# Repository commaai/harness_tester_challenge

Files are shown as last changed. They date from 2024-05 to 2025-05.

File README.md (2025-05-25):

<div align="center">
<h1>Harness Tester Challenge</h1>
<h3>
  <a href="https://comma.ai/leaderboard">Leaderboard</a>
  <span> · </span>
  <a href="https://comma.ai/jobs">comma.ai/jobs</a>
  <span> · </span>
  <a href="https://discord.comma.ai">Discord</a>
  <span> · </span>
  <a href="https://x.com/comma_ai">X</a>
</h3>
</div>

We (mock) designed a simple harness testing PCB and wrote some firmware for it. Unfortunately, this board was designed and firmware was written on a Monday morning.

<b>Can you figure out everything wrong with it?</b>

## The Harness Tester
We currently ship hundreds of [car-specific harnesses](https://www.comma.ai/shop/car-harness) to users every month, consisting of more than [40 different types](https://github.com/commaai/hardware/tree/master/harness/v3).

As a simple wiring harness, we expect them to have a near-zero failure rate, so good testing is critical.
This tester is designed to be capable of quickly verifying which pins are connected to which other pins.

A quick list of design goals is listed here:
- 12V DC input with transient and reverse polarity protection
- compatible with harnesses with up to 40 pins (through a pin header)
- start button and RGB LED are the user interface
- microSD card to store test results along with the current time (for statistical purposes)
- receive time by acquiring a GPS lock (*ok, yes, this is just to make the board and firmware more interesting*)

## The challenge
The challenge consists of 3 distinct parts, each riddled with more than a few bugs:
- Schematic ([PDF](./schematic.pdf) / [Web](https://kicanvas.org/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))
- PCB layout ([Gerbers](./gerbers.zip) / [Web](https://kicanvas.org/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))
- Firmware ([Source](./firmware/))

The board is designed in [KiCad 8](https://www.kicad.org/), and the full project is available in an [exported archive](./kicad_project.zip).

There are a handful of intentional, show-stopping bugs hidden in each part. Find them, and [send](https://forms.gle/US88Hg7UR6bBuW3BA) them over to us for verification!

We're not looking for improvements or fixes; just submit a list of bugs.

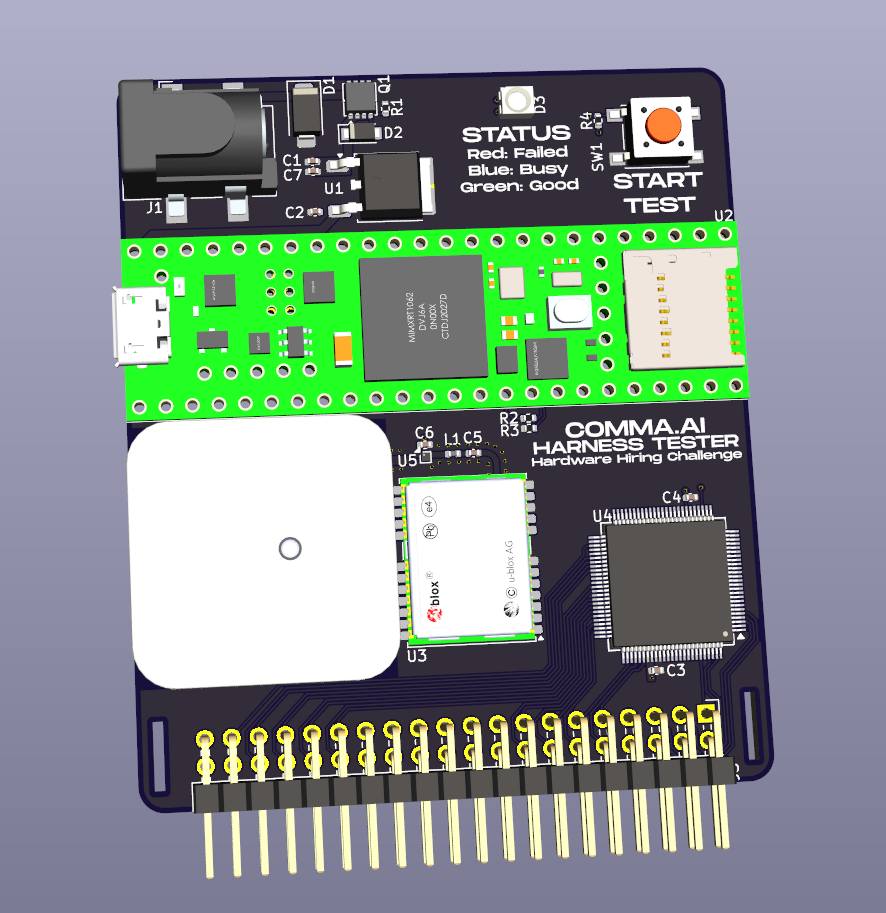
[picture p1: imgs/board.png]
PCB


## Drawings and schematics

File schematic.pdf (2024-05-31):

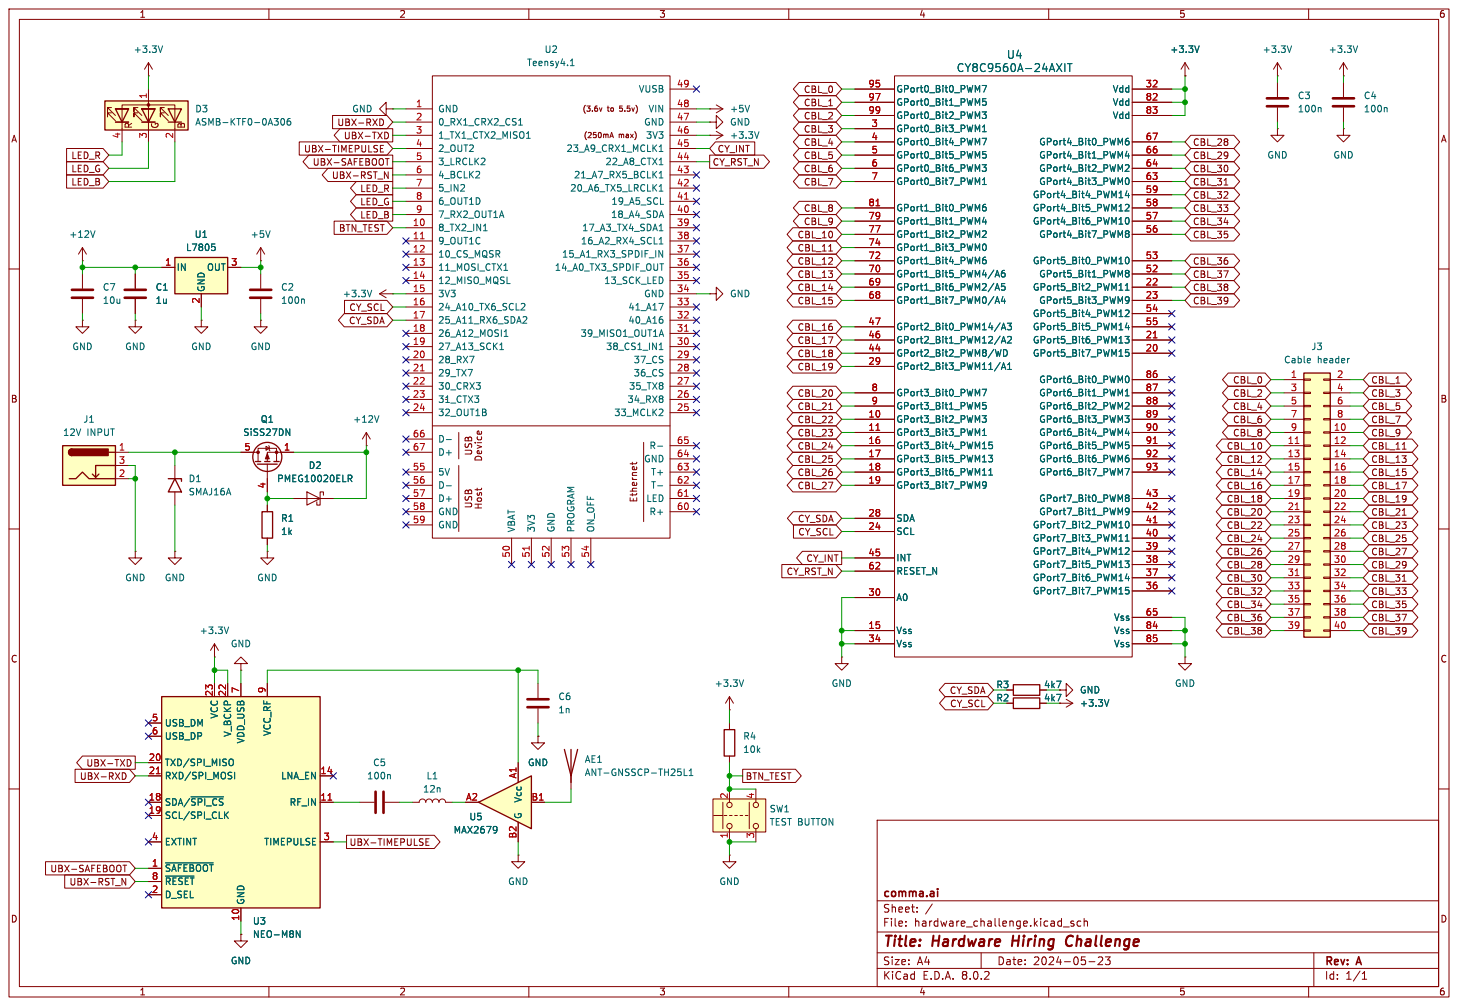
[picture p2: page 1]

UBX-TIMEPULSE UBX-TXD

3 4 SW1 TEST BUTTON GND GND

File: hardware_challenge.kicad_sch Sheet: / comma.ai C6

Id: 1/1 Title: Hardware Hiring Challenge

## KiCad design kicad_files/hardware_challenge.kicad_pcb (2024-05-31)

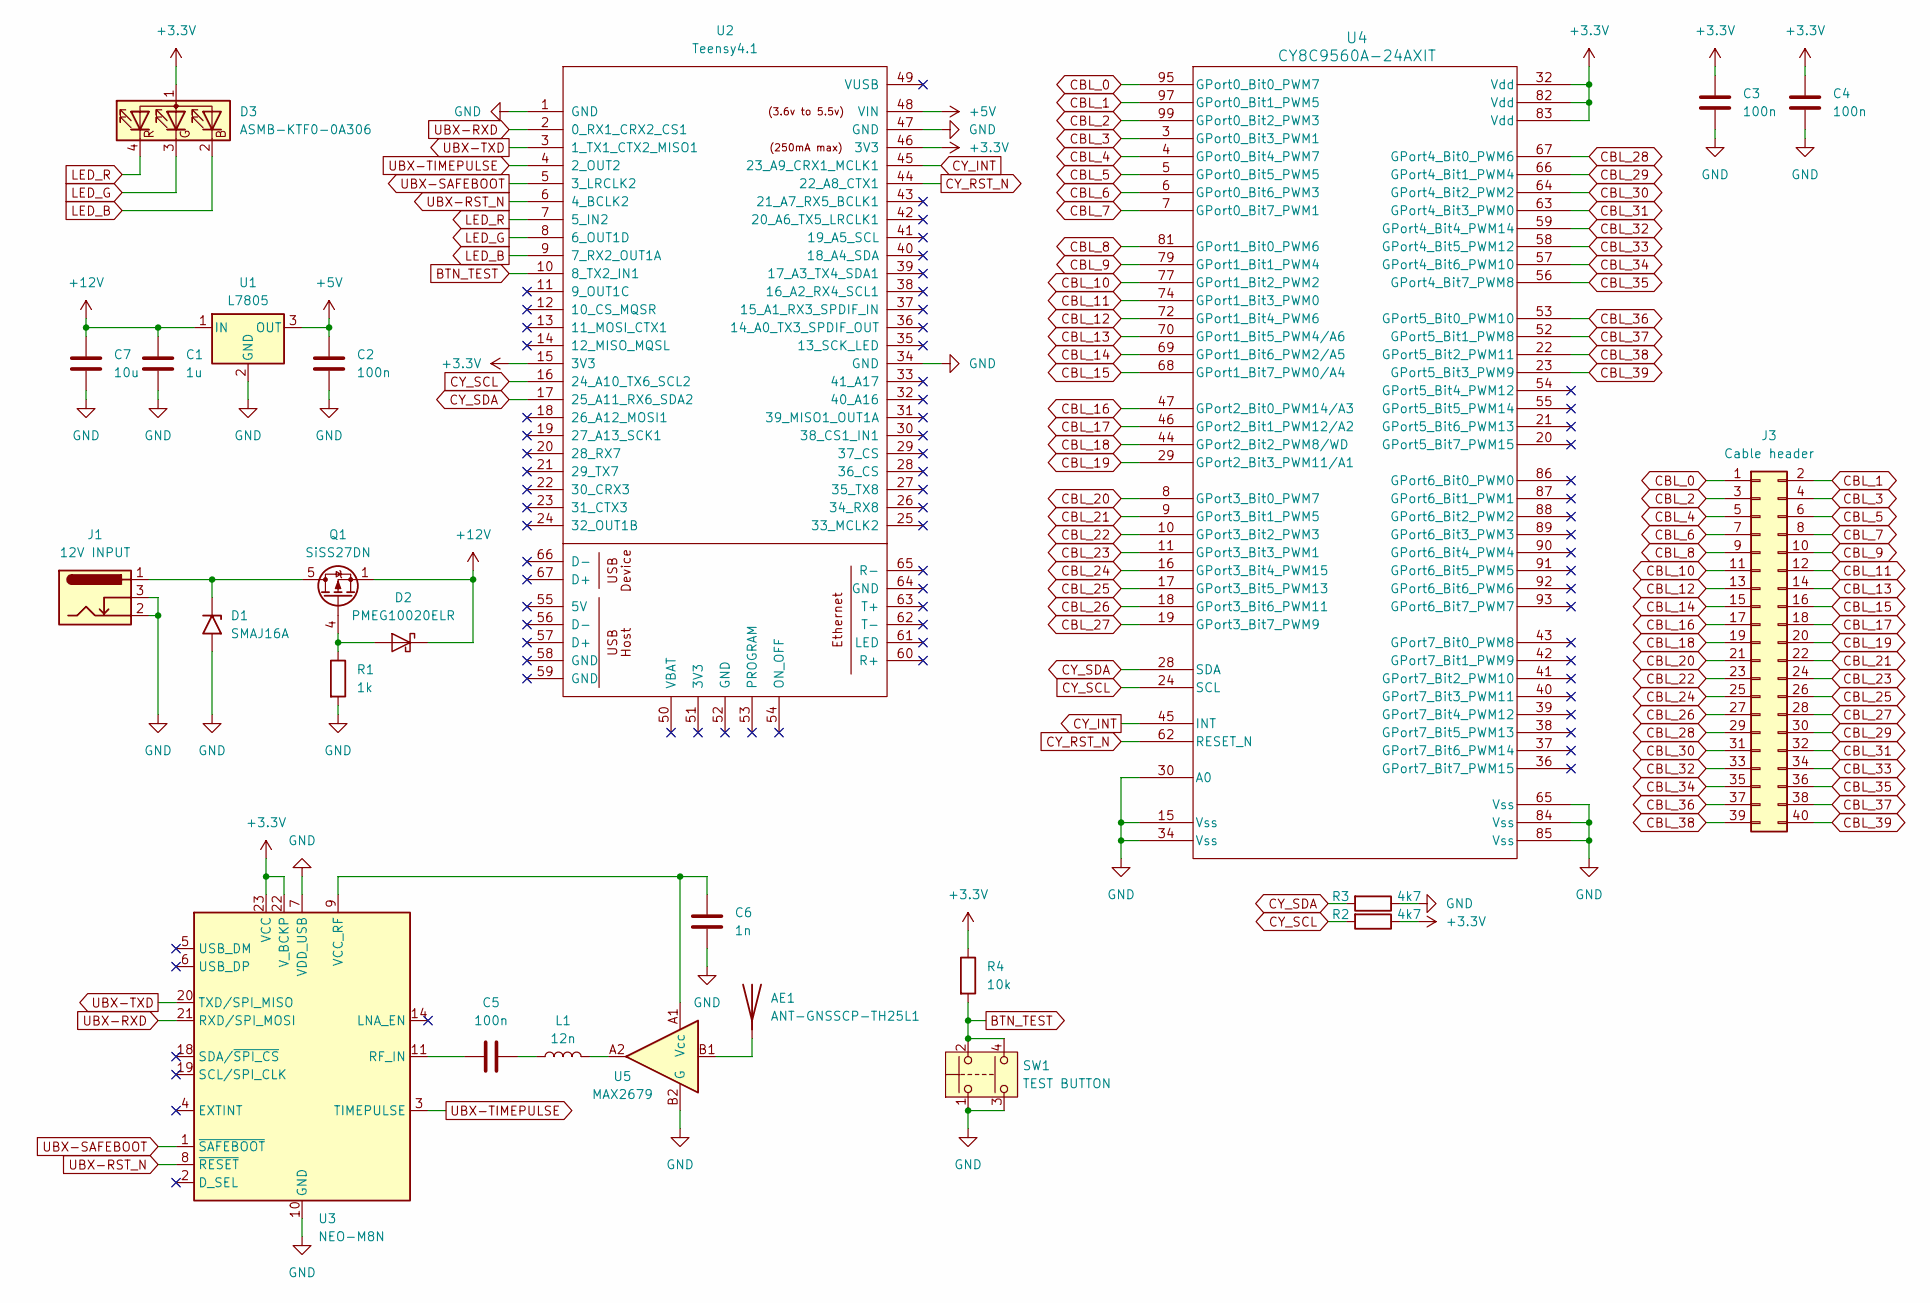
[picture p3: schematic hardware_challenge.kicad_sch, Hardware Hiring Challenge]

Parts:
AE1: ANT-GNSSCP-TH25L1
C1: 1u; C_0402_1005Metric
C2, C3, C4, C5: 100n; C_0402_1005Metric
C6: 1n; C_0402_1005Metric
C7: 10u; C_0402_1005Metric
D1: SMAJ16A; D_SMA
D2: PMEG10020ELR; Nexperia_CFP3_SOD-123W
D3: ASMB-KTF0-0A306; LED_ASMB-KTF0-0A306
J1: 12V INPUT; BarrelJack_CLIFF_FC681465S_SMT_Horizontal
J3: Cable header; PinHeader_2x20_P2.54mm_Horizontal
L1: 12n; L_0402_1005Metric
Q1: SiSS27DN; Vishay_PowerPAK_1212-8_Single
R1: 1k; R_0402_1005Metric
R2, R3: 4k7; R_0402_1005Metric
R4: 10k; R_0402_1005Metric
SW1: TEST BUTTON; SW_SPST_PTS645
U1: L7805; TO-252-2
U2: Teensy4.1; Teensy41
U3: NEO-M8N; ublox_NEO
U4: CY8C9560A-24AXIT; TQFP-100_12x12mm_P0.4mm
U5: MAX2679; WLP-4_0.83x0.83mm_P0.4mm

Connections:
+3.3V: C3.1, C4.1, D3.1 (A), R2.1, R4.1, U2.15 (3V3), U2.46 (3V3), U3.22 (V_BCKP), U3.23 (VCC), U4.32 (Vdd), U4.82 (Vdd), U4.83 (Vdd)
+5V: C2.1, U1.3 (OUT), U2.48 (VIN)
+12V: C1.1, C7.1, D2.1 (K), Q1.1 (S), Q1.2 (S), Q1.3 (S), U1.1 (IN)
BTN_TEST: R4.2, SW1.2, SW1.4, U2.10 (8_TX2_IN1)
CBL_0: J3.1, U4.95 (GPort0_Bit0_PWM7)
CBL_1: J3.2, U4.97 (GPort0_Bit1_PWM5)
CBL_2: J3.3, U4.99 (GPort0_Bit2_PWM3)
CBL_3: J3.4, U4.3 (GPort0_Bit3_PWM1)
CBL_4: J3.5, U4.4 (GPort0_Bit4_PWM7)
CBL_5: J3.6, U4.5 (GPort0_Bit5_PWM5)
CBL_6: J3.7, U4.6 (GPort0_Bit6_PWM3)
CBL_7: J3.8, U4.7 (GPort0_Bit7_PWM1)
CBL_8: J3.9, U4.81 (GPort1_Bit0_PWM6)
CBL_9: J3.10, U4.79 (GPort1_Bit1_PWM4)
CBL_10: J3.11, U4.77 (GPort1_Bit2_PWM2)
CBL_11: J3.12, U4.74 (GPort1_Bit3_PWM0)
CBL_12: J3.13, U4.72 (GPort1_Bit4_PWM6)
CBL_13: J3.14, U4.70 (GPort1_Bit5_PWM4/A6)
CBL_14: J3.15, U4.69 (GPort1_Bit6_PWM2/A5)
CBL_15: J3.16, U4.68 (GPort1_Bit7_PWM0/A4)
CBL_16: J3.17, U4.47 (GPort2_Bit0_PWM14/A3)
CBL_17: J3.18, U4.46 (GPort2_Bit1_PWM12/A2)
CBL_18: J3.19, U4.44 (GPort2_Bit2_PWM8/WD)
CBL_19: J3.20, U4.29 (GPort2_Bit3_PWM11/A1)
CBL_20: J3.21, U4.8 (GPort3_Bit0_PWM7)
CBL_21: J3.22, U4.9 (GPort3_Bit1_PWM5)
CBL_22: J3.23, U4.10 (GPort3_Bit2_PWM3)
CBL_23: J3.24, U4.11 (GPort3_Bit3_PWM1)
CBL_24: J3.25, U4.16 (GPort3_Bit4_PWM15)
CBL_25: J3.26, U4.17 (GPort3_Bit5_PWM13)
CBL_26: J3.27, U4.18 (GPort3_Bit6_PWM11)
CBL_27: J3.28, U4.19 (GPort3_Bit7_PWM9)
CBL_28: J3.29, U4.67 (GPort4_Bit0_PWM6)
CBL_29: J3.30, U4.66 (GPort4_Bit1_PWM4)
CBL_30: J3.31, U4.64 (GPort4_Bit2_PWM2)
CBL_31: J3.32, U4.63 (GPort4_Bit3_PWM0)
CBL_32: J3.33, U4.59 (GPort4_Bit4_PWM14)
CBL_33: J3.34, U4.58 (GPort4_Bit5_PWM12)
CBL_34: J3.35, U4.57 (GPort4_Bit6_PWM10)
CBL_35: J3.36, U4.56 (GPort4_Bit7_PWM8)
CBL_36: J3.37, U4.53 (GPort5_Bit0_PWM10)
CBL_37: J3.38, U4.52 (GPort5_Bit1_PWM8)
CBL_38: J3.39, U4.22 (GPort5_Bit2_PWM11)
CBL_39: J3.40, U4.23 (GPort5_Bit3_PWM9)
CY_INT: U2.45 (23_A9_CRX1_MCLK1), U4.45 (INT)
CY_RST_N: U2.44 (22_A8_CTX1), U4.62 (RESET_N)
CY_SCL: R2.2, U2.16 (24_A10_TX6_SCL2), U4.24 (SCL)
CY_SDA: R3.2, U2.17 (25_A11_RX6_SDA2), U4.28 (SDA)
GND: C1.2, C2.2, C3.2, C4.2, C6.2, C7.2, D1.2 (A2), J1.2, J1.3, R1.2, R3.1, SW1.1, SW1.3, U1.2 (GND), U2.1 (GND), U2.34 (GND), U2.47 (GND), U3.7 (VDD_USB), U3.10 (GND), U3.12 (GND), U3.13 (GND), U3.24 (GND), U4.15 (Vss), U4.30 (A0), U4.34 (Vss), U4.65 (Vss), U4.84 (Vss), U4.85 (Vss), U5.B2 (G)
LED_B: D3.2 (BK), U2.9 (7_RX2_OUT1A)
LED_G: D3.3 (GK), U2.8 (6_OUT1D)
LED_R: D3.4 (RK), U2.7 (5_IN2)
unnamed: AE1.1 (A), U5.B1
unnamed: C5.2, L1.1
unnamed: D1.1 (A1), J1.1, Q1.5 (D)
unnamed: D2.2 (A), Q1.4 (G), R1.1
unnamed: L1.2, U5.A2
unnamed: C5.1, U3.11 (RF_IN)
unnamed: C6.1, U3.9 (VCC_RF), U5.A1 (Vcc)
UBX-RST_N: U2.6 (4_BCLK2), U3.8 (~RESET)
UBX-RXD: U2.2 (0_RX1_CRX2_CS1), U3.21 (RXD/SPI_MOSI)
UBX-SAFEBOOT: U2.5 (3_LRCLK2), U3.1 (~SAFEBOOT)
UBX-TIMEPULSE: U2.4 (2_OUT2), U3.3 (TIMEPULSE)
UBX-TXD: U2.3 (1_TX1_CTX2_MISO1), U3.20 (TXD/SPI_MISO)

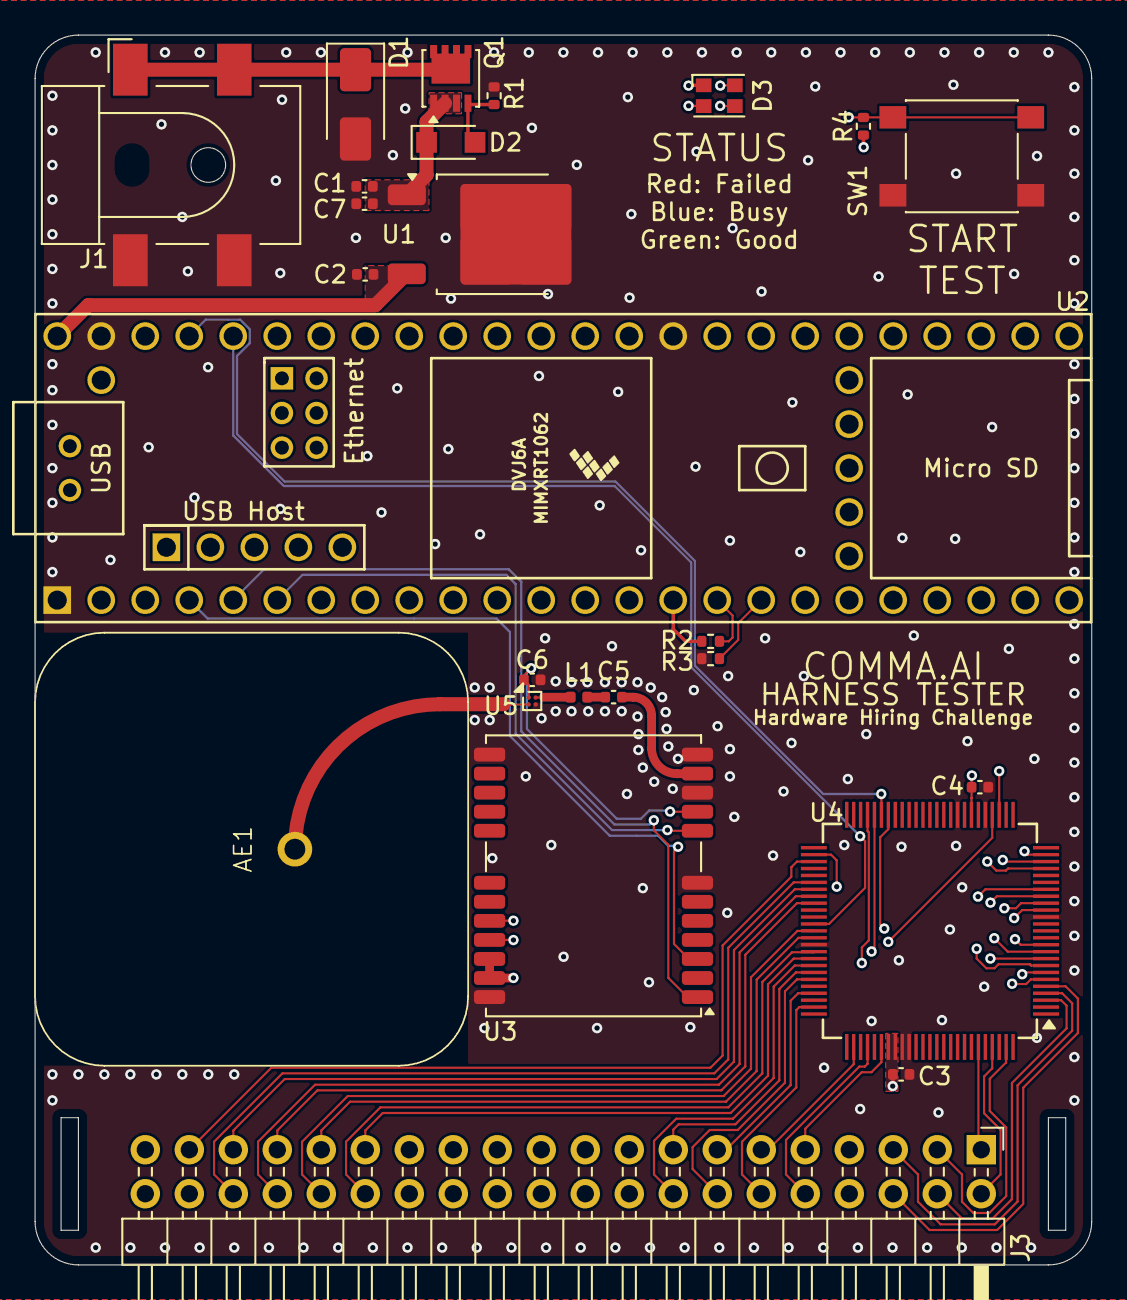
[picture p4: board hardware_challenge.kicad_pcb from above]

Board: 4 copper layers, 61.0 x 71.0 mm, 25 parts (0 on the bottom side), 64 nets.

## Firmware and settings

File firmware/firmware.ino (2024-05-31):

#include <SD.h>
#include "CY8C9560.h"

enum Status {FAILED, BUSY, GOOD};

#define PIN_UBX_TIMEPULSE 2
#define PIN_UBX_SAFEBOOT 3
#define PIN_UBX_RST_N 4
#define PIN_LED_R 5
#define PIN_LED_G 6
#define PIN_LED_B 7
#define PIN_BTN_TEST 8

#define DBG_SERIAL Serial
#define UBX_SERIAL Serial1
#define SD_CS BUILTIN_SDCARD

#define NUM_HARNESS_PINS 40
// Example connection matrix, just for illustration
uint64_t EXPECTED_CONNECTIONS[NUM_HARNESS_PINS] = {
  0b1000000000000000000000000010000000000000,
  0b0100001000000000000000000000000000000000,
  0b0010000000000000000000000000000000000000,
  0b0001100000001000000000000000000010000000,
  0b0000100000100000000000000001000000000000,
  0b0000010100000000000000000000000000000000,
  0b0000001000000000100000000000000000000000,
  0b0000000100000000000000000000001000001000,
  0b0000000010000000000000000000000000000000,
  0b0000000001000000000000000000000010000000,
  0b0010000000100000000000000000000000000000,
  0b0000000000010000000010000000000000000000,
  0b0000000000001000000000000000000000010000,
  0b0000000000000100000000000000000000000001,
  0b0000000000000010000000001000000000000000,
  0b0000000000001001000000000100000000000000,
  0b0000000000000000100000000000000000000000,
  0b0000010000000000010000000000000000000000,
  0b0000000000000000001000000000000000000000,
  0b0000000000000000000100000000100000000000,
  0b0000000000000000000010000000000000000000,
  0b0000000000000000000001000000000000000000,
  0b0000000000000000000000100000000000000000,
  0b0000000000000000000000010000000001000000,
  0b0000000000000000000000001000000000000000,
  0b0000000000001000000000000100000000000000,
  0b0000000000000000000000000010000000000000,
  0b0000000000100010000000001001000000001000,
  0b0000000000000000000000000000100000000000,
  0b0000000000001000000000000000010000010000,
  0b0000000000000000000000000000001000000000,
  0b0000000000000000000000000000000100000000,
  0b0000000000000000000000000000000010100000,
  0b0000000000000000000000000000000001000010,
  0b0000100000000000000000100000000000100000,
  0b0000010000000000000000000000000000011000,
  0b0000000000000000000000000000000000001000,
  0b0000000000000000000000000000010000000100,
  0b0000000000000000000000000000000000000010,
  0b0000000000000000000000000000000000000001,
};

CY8C9560 cy;
char utc_time[20], date[20];
bool time_fixed = false;

void set_status(Status s) {
  digitalWrite(PIN_LED_R, !(s == FAILED));
  digitalWrite(PIN_LED_B, !(s == BUSY));
  digitalWrite(PIN_LED_G, !(s == GOOD));
}

void process_nmea(char *buf, int len) {
  buf[len] = 0;
  if (strncmp(buf, "$GPRMC", 6) == 0) {
    if (sscanf(buf, "$GPRMC,%10[^,],%*c,%*f,%*c,%*f,%*c,%*f,%*f,%6[^,]", utc_time, date) == 2 && !time_fixed) {
      DBG_SERIAL.println("Time received. Ready to test some harnesses!");
      set_status(GOOD);
      time_fixed = true;
    } else if (!time_fixed) {
      DBG_SERIAL.println("Failed to parse $GPRMC");
    }
  }
}

void log_result(bool passed) {
  File f = SD.open("results.txt", FILE_WRITE);
  if (f) {
    f.print(date); f.print(" - "); f.print(utc_time); f.print(": "); // raw date + time strings are fine here
    f.println(passed ? "Passed" : "Failed");
    f.close();
  } else {
    DBG_SERIAL.println("Failed to open log file");
  }
}

void setup() {
  // Serial ports
  DBG_SERIAL.begin(115200);
  UBX_SERIAL.begin(9600);

  // GPIO
  set_status(BUSY);
  pinMode(PIN_BTN_TEST, INPUT);
  pinMode(PIN_UBX_TIMEPULSE, INPUT);
  digitalWrite(PIN_UBX_SAFEBOOT, LOW);
  digitalWrite(PIN_UBX_RST_N, HIGH);

  // SD card
  if (!SD.begin(SD_CS)) {
    DBG_SERIAL.println("SD card initialization failed");
    while (1);
  }

  DBG_SERIAL.println("Waiting for GPS time lock...");
}

char nmea_buf[64];
int nmea_idx = 0;
void loop() {
  // Process incoming ublox messages
  while (UBX_SERIAL.available()) {
    nmea_buf[nmea_idx++] = UBX_SERIAL.read();
    if (nmea_buf[nmea_idx - 1] == '\n' || nmea_buf[nmea_idx - 1] == '\r') {
      process_nmea(nmea_buf, nmea_idx);
      nmea_idx = 0;

      // Jump out the while here to make sure we're not missing any button presses under high load
      break;
    }
  }

  // Return if we don't have a time fix yet
  if (!time_fixed) return;
  set_status(GOOD);

  // Start testing only if the button is pressed
  if (digitalRead(PIN_BTN_TEST) == LOW) return;
  set_status(BUSY);

  // Test harness by checking the connectivity of every pin
  bool passed = false;
  for (int i = 0; i < NUM_HARNESS_PINS; i++) {
    uint64_t output_mask = 1 << i;
    cy.set_output(output_mask, output_mask);
    cy.set_pd_inputs(~output_mask);

    uint64_t values = cy.read_inputs() & ~output_mask;

    // Log connections to the serial port
    DBG_SERIAL.printf("Pin %d: ", i);
    for (int j = 0; j < NUM_HARNESS_PINS; j++) DBG_SERIAL.printf("%d", (values & (1 << j)) ? 1 : 0);
    DBG_SERIAL.println();

    if (values == EXPECTED_CONNECTIONS[i]) {
      passed = true;
    }
  }

  // Show and log results
  DBG_SERIAL.println(passed ? "Harness passed!" : "Harness failed!");
  log_result(passed);
  set_status(passed ? GOOD : FAILED);
}

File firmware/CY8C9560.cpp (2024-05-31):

#include "CY8C9560.h"

bool CY8C9560::begin() {
  pinMode(CY_IRQ_N, INPUT_PULLUP);
  pinMode(CY_RST, OUTPUT);
  digitalWrite(CY_RST, HIGH);
  delay(10);
  digitalWrite(CY_RST, LOW);
  delay(100);

  WIRE.begin();
  WIRE.setClock(100000);

  return read_id() == 0x06;
}

uint8_t CY8C9560::read_register(uint8_t reg) {
  WIRE.beginTransmission(addr);
  WIRE.write(reg);
  WIRE.endTransmission(false);
  WIRE.requestFrom(addr, 1U);
  return WIRE.read();
}

uint64_t CY8C9560::read_registers(uint8_t reg_base, uint8_t len) {
  WIRE.beginTransmission(addr);
  WIRE.write(reg_base);
  WIRE.endTransmission(false);
  WIRE.requestFrom(addr, len);
  uint64_t registers = 0;
  for (int i = 0; i < len; i++) {
    registers |= (uint64_t)WIRE.read() << (i * 8);
  }
  return registers;
}

void CY8C9560::write_register(uint8_t reg, uint8_t data) {
  WIRE.beginTransmission(addr);
  WIRE.write(reg);
  WIRE.write(data);
  WIRE.endTransmission();
}

void CY8C9560::write_registers(uint8_t reg_base, uint64_t data, uint8_t len) {
  WIRE.beginTransmission(addr);
  WIRE.write(reg_base);
  for (int i = 0; i < len; i++) {
    WIRE.write((uint8_t) (data >> (i * 8)));
  }
  WIRE.endTransmission();
}

uint8_t CY8C9560::read_id() {
  return (read_register(REG_DEVICE_ID_STATUS) >> 4) & 0x0F;
}

uint64_t CY8C9560::read_inputs() {
  return read_registers(REG_INPUT_BASE, 8);
}

void CY8C9560::set_pd_inputs(uint64_t pins) {
  for (int i = 0; i < 8; i++) {
    write_register(REG_PORT_SELECT, i);
    write_register(REG_PIN_DIRECTION, 0xFF);
    write_register(REG_PIN_DRIVE_MODE_BASE + DRIVE_MODE_PULL_DOWN, pins >> (i * 8));
  }
}

void CY8C9560::set_pu_inputs(uint64_t pins) {
  for (int i = 0; i < 8; i++) {
    write_register(REG_PORT_SELECT, i);
    write_register(REG_PIN_DIRECTION, 0xFF);
    write_register(REG_PIN_DRIVE_MODE_BASE + DRIVE_MODE_PULL_UP, pins >> (i * 8));
  }
}

void CY8C9560::set_output(uint64_t pins, uint64_t values) {
  write_registers(REG_OUTPUT_BASE, values, 8);
  for (int i = 0; i < 8; i++) {
    write_register(REG_PORT_SELECT, i);
    write_register(REG_PIN_DIRECTION, 0x00);
    write_register(REG_PIN_DRIVE_MODE_BASE + DRIVE_MODE_STRONG, pins >> (i * 8));
  }
}
